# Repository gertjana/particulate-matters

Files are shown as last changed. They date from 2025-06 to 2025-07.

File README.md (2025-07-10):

# Particulate Matter Bike Monitor

This project is a mobile air quality monitoring system designed to be mounted on a bicycle. It measures fine particulate matter (PM1, PM2.5, and PM10) and records GPS location data during your commute. The collected data is stored locally on an SD card and displayed in real-time on an OLED screen, enabling you to create heatmaps of air pollution along your cycling routes.

## Features

- **Real-time air quality monitoring:** Measures PM1, PM2.5, and PM10 concentrations using the BMV080 particulate matter sensor.
- **GPS tracking:** Captures latitude, longitude, and timestamp for each measurement.
- **Local data storage:** Saves measurements to SD card with date-based file organization.
- **Real-time display:** Shows current readings and GPS coordinates on an OLED display.
- **Sensor health monitoring:** Detects when the sensor is obstructed and displays warnings.

## Hardware Requirements

- Arduino-compatible board (ESP32 recommended for SD card support)
- BMV080 Particulate Matter Sensor (I2C)
- GPS module (compatible with TinyGPS++)
- OLED Display (SSD1306, 128x32)
- SD Card Module (SPI)
- Battery pack
- Bicycle mounting hardware

## Pin Configuration

- **I2C (Wire):** SDA, SCL - for BMV080 sensor and OLED display
- **SPI (SD Card):** CS:44, MOSI:9, MISO:8, CLK:7
- **GPS (Software Serial):** TX:3, RX:2

## System Architecture

The system operates on a 10-second measurement interval and includes:

1. **Data Collection:** Reads PM1, PM2.5, PM10, and GPS coordinates
2. **Data Processing:** Packages data into JSON format
3. **Local Storage:** Saves to SD card with date-based filenames
4. **Real-time Display:** Shows current readings on OLED screen

System Architecture

## Data Format

Each measurement is stored as a JSON object with the following structure:

```json
{
  "pm": {
    "pm1": 15,
    "pm2.5": 25,
    "pm10": 45,
    "obstructed": false
  },
  "gps": {
    "date": "15-12-2024",
    "time": "14:30:25",
    "latitude": "52.12345678",
    "longitude": "4.87654321"
  }
}
```

## File Organization

Data is stored on the SD card with the following structure:

- Files are named by date: `DD-MM-YYYY.txt`
- Each line contains one JSON measurement
- Files are created automatically when data is available

## Setup

1. Clone this repository.
2. Install required libraries:
   - SparkFun_BMV080_Arduino_Library
   - TinyGPSPlus
   - ArduinoJson
   - Adafruit_GFX
   - Adafruit_SSD1306
3. Connect hardware according to pin configuration
4. Insert formatted SD card
5. Upload `dust_sensor_new/dust_sensor_new.ino` to your Arduino board
6. Mount the device on your bike and power it up before your ride

## Debug Mode

The system includes comprehensive debug output when `DEBUG` is defined. This includes:

- SD card information (type, size, free space)
- Sensor initialization status
- GPS data processing
- File writing operations

To enable debug mode, ensure `#define DEBUG` is uncommented in the code.

## Data Analysis

### Local Analysis

- Data files can be read directly from the SD card
- JSON format makes it easy to parse with any programming language
- Each measurement includes timestamp and location data

### Heatmap Generation

For setting up and using the heatmap visualization, see [heatmap/README.md](heatmap/README.md)

See [`example.md`](example.md) for sample data format and structure.

## License

MIT License

## Contributing

Contributions are welcome! Please open an issue or submit a pull request.

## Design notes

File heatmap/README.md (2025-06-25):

# Heatmap Visualization

This folder contains scripts to visualize particulate matter measurements on interactive heatmaps.

## Prerequisites
- Python 3.x installed
- pip (Python package installer)
- A JSON file with measurements from The Things Network (provided in `stored_messages_*.json`)

## Setup Instructions

1. Create and activate Python virtual environment:
```fish
# From the project root
python3 -m venv venv

# Activate the virtual environment (for fish shell)
source venv/bin/activate.fish
```

2. Install required packages:
```fish
pip install folium
```

## Generating Heatmaps

Make sure your virtual environment is activated (you should see `(venv)` in your prompt), then:

1. Navigate to this directory:
```fish
cd heatmap
```

2. Run the heatmap generator:
```fish
python create_heatmap.py
```

The script will generate two HTML files:
- `heatmap_pm10_[timestamp].html`: Heatmap showing PM10 concentrations
- `heatmap_pm25_[timestamp].html`: Heatmap showing PM2.5 concentrations

## Viewing the Heatmaps

Open the generated HTML files in a web browser. Each heatmap shows:
- Interactive map with color-coded concentrations
  - Blue: Low concentration
  - Green: Medium-low concentration
  - Yellow: Medium-high concentration
  - Red: High concentration
- Legend box showing:
  - Measurement ranges for each color
  - Total range of measurements
  - Number of samples
- Timestamp in the filename

You can:
- Zoom in/out of the map
- Pan around
- Hover over areas to see concentration intensity

## Managing the Virtual Environment

When you're done, deactivate the virtual environment:
```fish
deactivate
```

To reactivate it later:
```fish
source venv/bin/activate.fish
```

## Input Data Format

The script expects a JSON file (`stored_messages_*.json`) containing measurements from The Things Network with the following structure for each measurement:
```json
{
  "uplink_message": {
    "decoded_payload": {
      "pm10": <number>,
      "pm25": <number>
    },
    "locations": {
      "frm-payload": {
        "latitude": <number>,
        "longitude": <number>
      }
    }
  }
}
```

For more details about the data format and byte structure, see `../example.md`.

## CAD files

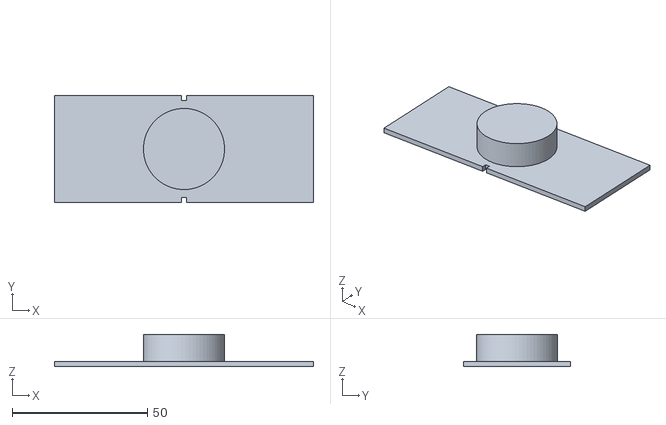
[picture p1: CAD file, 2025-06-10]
3d/Case_Side_Quadlockl_module.stl
95.8 x 39.5 x 12.0

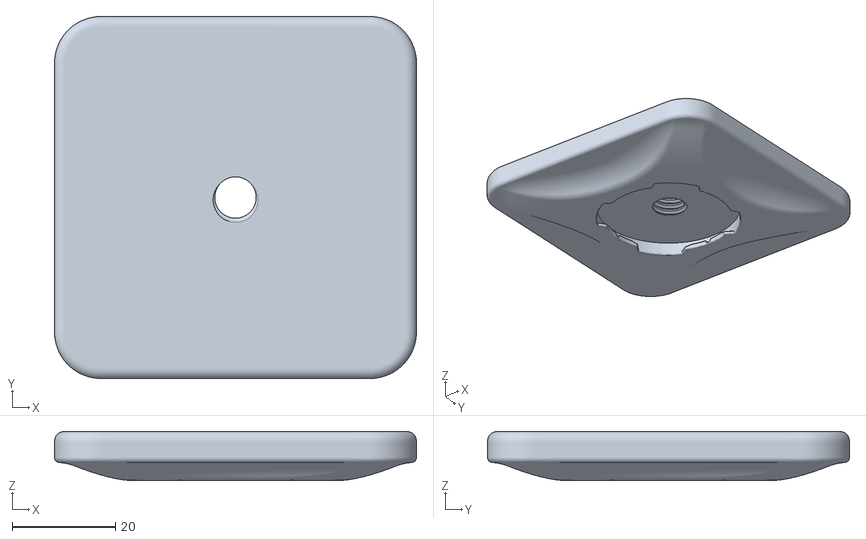
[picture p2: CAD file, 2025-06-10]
3d/quad_lock_adapter_v2.stl
70.0 x 70.0 x 9.50

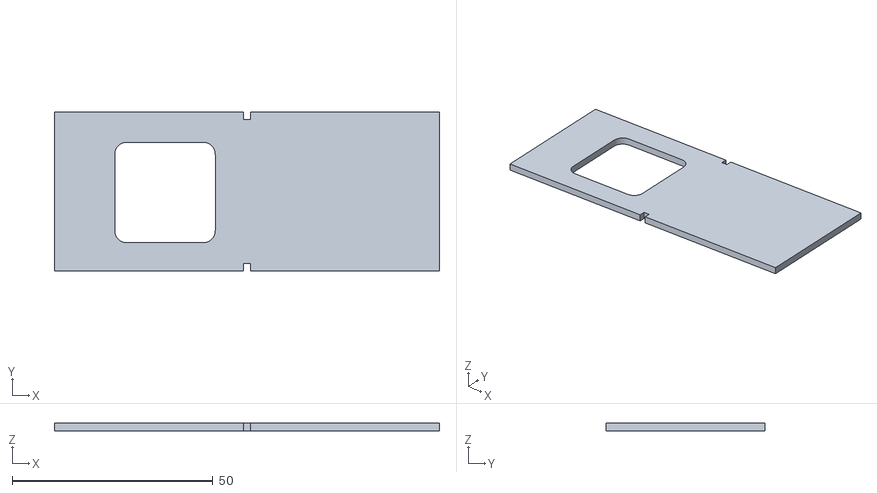
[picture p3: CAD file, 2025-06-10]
3d/Case_Side_GPS_module.stl
95.8 x 39.5 x 2.00

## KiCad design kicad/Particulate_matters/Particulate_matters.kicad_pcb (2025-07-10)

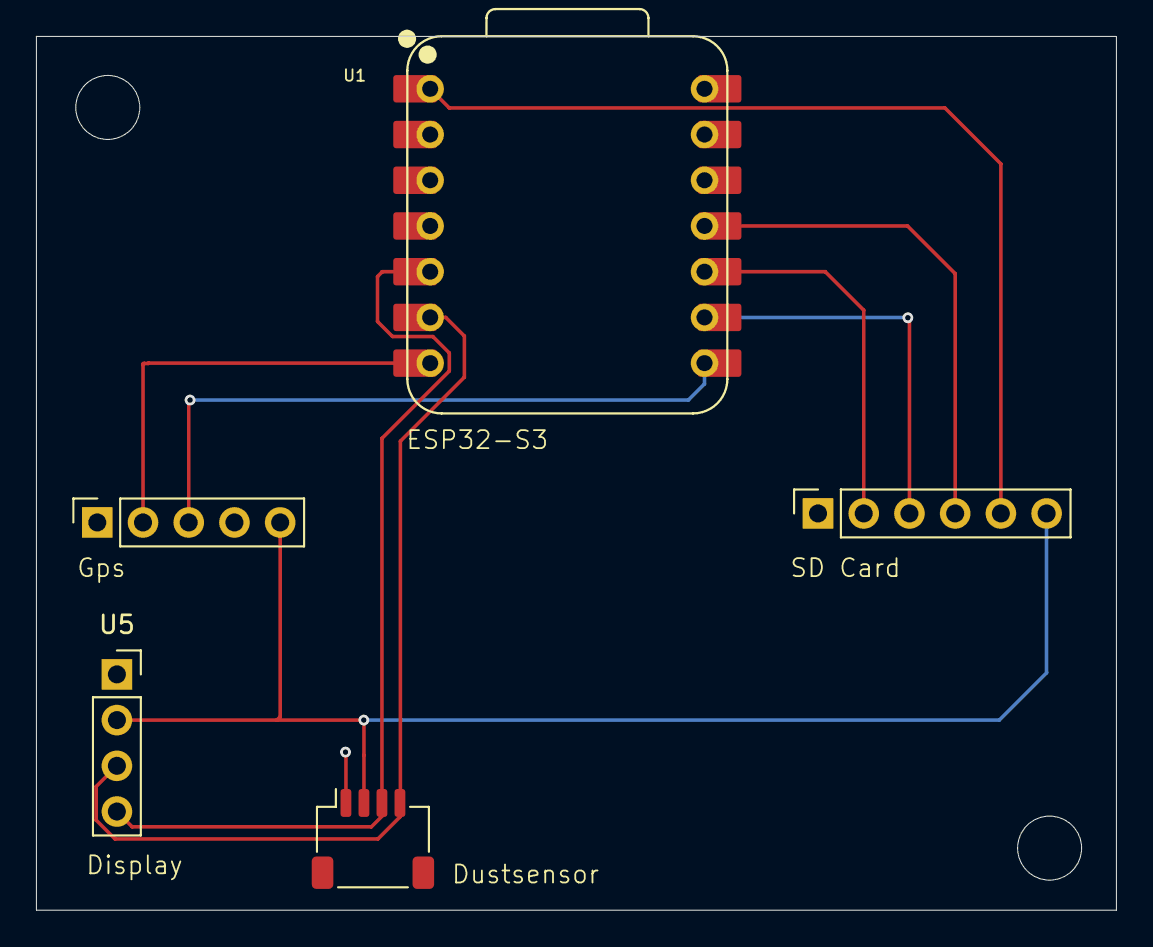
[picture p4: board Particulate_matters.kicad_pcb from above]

Board: 2 copper layers, 60.0 x 48.5 mm, 5 parts (0 on the bottom side), 10 nets.

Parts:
U1: XIAO-ESP32-S3-DIP; XIAO-ESP32S3-DIP
U2: PinSocket_1x05_P2.54mm_Vertical
U3: JST_SH_SM04B-SRSS-TB_1x04-1MP_P1.00mm_Horizontal
U4: PinSocket_1x06_P2.54mm_Vertical
U5: PinSocket_1x04_P2.54mm_Vertical

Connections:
GND: U1.13 (GND), U2.4 (GND), U3.1 (GND), U4.1 (GND), U5.1 (GND)
unnamed: U1.1 (GPIO1/D0/A0), U4.5 (CS)
unnamed: U1.5 (GPIO5/D4/I2C_SDA), U3.3 (SDA), U5.4 (SDA)
unnamed: U1.9 (GPIO7/D8/A8/SCK), U4.3 (CLK)
unnamed: U1.10 (GPIO8/D9/A9/MISO), U4.2 (MISO)
unnamed: U1.6 (GPIO9/D5/I2C_SCL), U3.4 (SDL), U5.3 (SCK)
unnamed: U1.11 (GPIO9/D10/A10/MOSI), U4.4 (MOSI)
unnamed: U1.8 (U0RXD/D7/RX), U2.3 (TX)
unnamed: U1.7 (U0TXD/D6/TX), U2.2 (RX)
VCC: U1.12 (VCC_3V3), U2.5 (VCC), U3.2 (VCC), U4.6 (3V3), U5.2 (VCC)

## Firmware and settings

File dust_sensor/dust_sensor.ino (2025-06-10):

#include <TheThingsNetwork.h>
#include <TinyGPSPlus.h>
#include <SoftwareSerial.h>
#include <math.h>

#include "secrets.h"

#define loraSerial Serial1
#define debugSerial Serial

#define DUST_SENSOR_DIGITAL_PIN_PM10  6
#define DUST_SENSOR_DIGITAL_PIN_PM25  3

#define QUEUE_SIZE 10  // Size of the circular queue
#define DATA_SIZE 20   // Size of each data packet

#define freqPlan TTN_FP_EU868

const int port = 3;
unsigned long lastMeasurement = 0;
const unsigned long MEASURE_INTERVAL = 60000; // Measure every minute

// Circular queue implementation
struct Queue {
    byte data[QUEUE_SIZE][DATA_SIZE];
    int front;
    int rear;
    int count;
};

Queue measurementQueue = {{}, 0, 0, 0};

// Function declarations
void initQueue();
bool isQueueFull();
bool isQueueEmpty();
bool enqueue(byte* data);
bool dequeue(byte* data);
    
TheThingsNetwork ttn(loraSerial, debugSerial, freqPlan);

SoftwareSerial gpsSerial(10, 11);
TinyGPSPlus gps;

typedef union
{
 float number;
 uint8_t bytes[4];
} FLOATUNION_t;

// GPS Values
FLOATUNION_t lat;
FLOATUNION_t lng;
signed int altitude;

//dust sensor variables
float lastDUSTPM25 = 0.0;
float lastDUSTPM10 = 0.0;
unsigned long duration;
unsigned long starttime;
unsigned long endtime;
unsigned long sampletime_ms = 15000;
unsigned long lowpulseoccupancy = 0;
float ratio = 0;
long concentrationPM25 = 0;
long concentrationPM10 = 0;

int cnt = 0;

void setup() {
    pinMode(DUST_SENSOR_DIGITAL_PIN_PM10, INPUT);
    pinMode(DUST_SENSOR_DIGITAL_PIN_PM25, INPUT);
    
    loraSerial.begin(57600);
    debugSerial.begin(9600);
    gpsSerial.begin(9600);

    // Wait a maximum of 10s for Serial Monitor
    while (!debugSerial && millis() < 10000);

    debugSerial.println("-- STATUS");
    ttn.showStatus();

    debugSerial.println("-- JOIN");
    ttn.join(appEui, appKey);

    ttn.onMessage(message);
    initQueue();
}

void loop() {
    measureTask();
    sendTask();
}

void measureTask() {
    if (millis() - lastMeasurement < MEASURE_INTERVAL) {
        return;
    }

    byte data[DATA_SIZE] = {0};
    
    debugSerial.println("-- Measure PM");

    concentrationPM25 = getPM(DUST_SENSOR_DIGITAL_PIN_PM25);
    debugSerial.print("PM25: ");
    debugSerial.println(concentrationPM25);

    if ((ceil(concentrationPM25) != lastDUSTPM25) && ((long)concentrationPM25 > 0)) {
        data[0] = (byte)(concentrationPM25 >> 8);
        data[1] = (byte)concentrationPM25;
        lastDUSTPM25 = ceil(concentrationPM25);
    }

    concentrationPM10 = getPM(DUST_SENSOR_DIGITAL_PIN_PM10);
    debugSerial.print("PM10: ");
    debugSerial.println(concentrationPM10);
    
    if ((ceil(concentrationPM10) != lastDUSTPM10) && ((long)concentrationPM10 > 0)) {
        data[2] = (byte)(concentrationPM10 >> 8);
        data[3] = (byte)concentrationPM10;
        lastDUSTPM10 = ceil(concentrationPM10);
    }

    while (gpsSerial.available()) {
        gps.encode(gpsSerial.read());
    }

    lat.number = gps.location.lat();
    lng.number = gps.location.lng();
    altitude = gps.altitude.meters();

    data[4] = lat.bytes[3];
    data[5] = lat.bytes[2];
    data[6] = lat.bytes[1];
    data[7] = lat.bytes[0];
    
    data[8] = lng.bytes[3];
    data[9] = lng.bytes[2];
    data[10] = lng.bytes[1];
    data[11] = lng.bytes[0];
    
    data[12] = altitude;

    data[13] = gps.date.year() >> 8;
    data[14] = gps.date.year();
    data[15] = gps.date.month();
    data[16] = gps.date.day();
    data[17] = gps.time.hour();
    data[18] = gps.time.minute();
    data[19] = gps.time.second();

    if (enqueue(data)) {
        debugSerial.println("Measurement added to queue");
    } else {
        debugSerial.println("Queue full - measurement dropped");
    }

    lastMeasurement = millis();
}

void sendTask() {
    if (isQueueEmpty()) {
        return;  // Nothing to send
    }

    byte dataToSend[DATA_SIZE];
    
    memcpy(dataToSend, measurementQueue.data[measurementQueue.front], DATA_SIZE);
    
    debugSerial.println("-- Sending...");
    if (ttn.sendBytes(dataToSend, DATA_SIZE, port) == TTN_SUCCESSFUL_TRANSMISSION) {
        byte dummy[DATA_SIZE];
        dequeue(dummy);
        cnt = 0;
    } else {
        debugSerial.println("Transmission failed - keeping message in queue");
        cnt++;
    }
}

void initQueue() {
    measurementQueue.front = 0;
    measurementQueue.rear = 0;
    measurementQueue.count = 0;
}

bool isQueueFull() {
    return measurementQueue.count >= QUEUE_SIZE;
}

bool isQueueEmpty() {
    return measurementQueue.count == 0;
}

bool enqueue(byte* data) {
    if (isQueueFull()) {
        return false;
    }
    
    memcpy(measurementQueue.data[measurementQueue.rear], data, DATA_SIZE);
    measurementQueue.rear = (measurementQueue.rear + 1) % QUEUE_SIZE;
    measurementQueue.count++;
    return true;
}

bool dequeue(byte* data) {
    if (isQueueEmpty()) {
        return false;
    }
    
    memcpy(data, measurementQueue.data[measurementQueue.front], DATA_SIZE);
    measurementQueue.front = (measurementQueue.front + 1) % QUEUE_SIZE;
    measurementQueue.count--;
    return true;
}

void message(const byte* payload, int length, int port) {
    debugSerial.println("-- MESSAGE");
    return;
}

long getPM(int DUST_SENSOR_DIGITAL_PIN) {

  starttime = millis();
  while (1) {
  
    duration = pulseIn(DUST_SENSOR_DIGITAL_PIN, LOW);
    lowpulseoccupancy += duration;
    endtime = millis();
    
    if ((endtime-starttime) > sampletime_ms)
    {
    ratio = (lowpulseoccupancy-endtime+starttime)/(sampletime_ms*10.0);  // Integer percentage 0=>100
    long concentration = 1.1*pow(ratio,3)-3.8*pow(ratio,2)+520*ratio+0.62; // using spec sheet curve

    
    lowpulseoccupancy = 0;
    return(concentration);    
    }
  }  
}

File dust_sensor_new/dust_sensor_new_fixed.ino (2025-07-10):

#include "SparkFun_BMV080_Arduino_Library.h" 
#include <Wire.h>
#include <TinyGPSPlus.h>
#include <SoftwareSerial.h>
#include <ArduinoJson.h>
#include <FS.h>
#include <SD.h>
#include <SPI.h>
#include <Adafruit_GFX.h>
#include <Adafruit_SSD1306.h>

#define SCREEN_WIDTH 128 
#define SCREEN_HEIGHT 32 
#define OLED_RESET     -1 // Reset pin # (or -1 if sharing Arduino reset pin)

#define BMV080_ADDR 0x57
#define wirePort Wire

#define SD_CS 44
#define SD_MOSI 9
#define SD_MISO 8
#define SD_CLK 7

#define GPS_RX 2
#define GPS_TX 3
#define GPS_BAUD 9600

#define INTERVAL 10000 
#define JSON_DOC_SIZE 512  // Explicit JSON document size

#define DEBUG

TinyGPSPlus gps;
SoftwareSerial gpsSerial(GPS_TX, GPS_RX);

SparkFunBMV080 bmv080; 

Adafruit_SSD1306 display(SCREEN_WIDTH, SCREEN_HEIGHT, &Wire, OLED_RESET);

// Global flags for system status
bool sdCardAvailable = false;
bool sensorAvailable = false;
bool displayAvailable = false;

void setup()
{
    Serial.begin(115200);
    while (!Serial && millis() < 10000);

    // Initialize display
    if(!display.begin(SSD1306_SWITCHCAPVCC, 0x3C)) { 
        Serial.println(F("SSD1306 allocation failed"));
    } else {
        displayAvailable = true;
        display.clearDisplay();
        display.setTextSize(1);
        display.setTextColor(WHITE);
        display.println("Particulate Matters");
        display.display();
    }

    // Initialize GPS
    gpsSerial.begin(GPS_BAUD);

    // Initialize SD card
    pinMode(SD_CS, OUTPUT);
    if(!SD.begin()){
        Serial.println("Card Mount Failed");
    } else {
        uint8_t cardType = SD.cardType();
        if(cardType == CARD_NONE){
            Serial.println("No SD card attached");
        } else {
            sdCardAvailable = true;
            #ifdef DEBUG
                Serial.print("SD Card Type: ");
                if(cardType == CARD_MMC){
                    Serial.println("MMC");
                } else if(cardType == CARD_SD){
                    Serial.println("SDSC");
                } else if(cardType == CARD_SDHC){
                    Serial.println("SDHC");
                } else {
                    Serial.println("UNKNOWN");
                }
                
                uint64_t cardSize = SD.cardSize()/(1024*1024);
                Serial.printf("SD Card Size: %lluMB\n", cardSize);
                Serial.printf("SD Free: %lluMB\n", cardSize-(SD.usedBytes()/(1024*1024)));
            #endif
        }
    }

    // Initialize I2C
    wirePort.begin();

    // Initialize BMV080 sensor
    if (bmv080.begin(BMV080_ADDR, wirePort) == false) {
        Serial.println("BMV080 not detected at default I2C address. Check your jumpers and the hookup guide.");
    } else {
        sensorAvailable = true;
        #ifdef DEBUG
            Serial.println("BMV080 found!");
        #endif

        bmv080.init();

        if (bmv080.setMode(SF_BMV080_MODE_CONTINUOUS) == true) {   
            #ifdef DEBUG
                Serial.println("BMV080 set to continuous mode");
            #endif  
        } else {
            Serial.println("Error setting BMV080 mode");
            sensorAvailable = false;
        }
    }

    // Display system status
    if (displayAvailable) {
        display.clearDisplay();
        display.setCursor(0,0);
        display.println("System Status:");
        display.printf("SD: %s\n", sdCardAvailable ? "OK" : "FAIL");
        display.printf("Sensor: %s\n", sensorAvailable ? "OK" : "FAIL");
        display.display();
        delay(2000);
    }
}

String zeroPad(int number, int width) {
    char buffer[10];
    if (width > 9) width = 9; // Prevent buffer overflow
    sprintf(buffer, "%0*d", width, number);
    return String(buffer);
}

bool appendFile(fs::FS &fs, JsonDocument &doc) {
    if (!sdCardAvailable) {
        return false;
    }
    
    if (!doc["gps"]["date"]) { 
        return false;
    }
    
    String path = String("/") + String(doc["gps"]["date"]) + String(".txt");
    
    #ifdef DEBUG
        Serial.printf("Writing to %s\n", path.c_str()); 
    #endif
    
    char output[256];
    if (serializeJson(doc, output, sizeof(output)) == 0) {
        Serial.println("JSON serialization failed");
        return false;
    }
    
    File file = fs.open(path.c_str(), FILE_APPEND);
    if(!file){
        Serial.printf("Failed to open file for appending, creating %s\n", path.c_str());
        File file2 = fs.open(path.c_str(), FILE_WRITE);
        if (!file2) {
            Serial.println("Failed to create new file");
            return false;
        }
        file2.println(output);
        file2.close();
    } else {
        file.println(output);
        file.close();
    }
    
    return true;
}

void getGPS(JsonDocument &doc) {
    JsonObject gpsObj = doc.createNestedObject("gps");
    bool hasValidData = false;
    
    while (gpsSerial.available() > 0) {
        #ifdef DEBUG
            Serial.print(char(gpsSerial.peek()));
        #endif

        if (gps.encode(gpsSerial.read())) {
            if (gps.date.isValid()) {
                gpsObj["date"] = zeroPad(gps.date.day(), 2) + "-" + zeroPad(gps.date.month(), 2) + "-" + String(gps.date.year());
                hasValidData = true;
            }
            if (gps.time.isValid()) {
                gpsObj["time"] = zeroPad(gps.time.hour(), 2) + ":" + zeroPad(gps.time.minute(), 2) + ":" + zeroPad(gps.time.second(), 2);
                hasValidData = true;
            }
            if (gps.location.isValid()) {
                gpsObj["latitude"] = String(gps.location.lat(), 8);
                gpsObj["longitude"] = String(gps.location.lng(), 8);
                hasValidData = true;
            }
        }
    }

    #ifdef DEBUG
        if (hasValidData) {
            Serial.println("GPS data updated");
        }
        Serial.println();
    #endif
}

void getPM(JsonDocument &doc) {
    JsonObject pmObj = doc.createNestedObject("pm");

    if (sensorAvailable && bmv080.readSensor()) {
        pmObj["pm1"] = bmv080.PM1();
        pmObj["pm2.5"] = bmv080.PM25();
        pmObj["pm10"] = bmv080.PM10();
        pmObj["obstructed"] = bmv080.isObstructed();
    }
}
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

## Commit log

2018-02-22 Arduino sketch to send ppd42 sensor data through lora
2025-06-03 Added temperature
2025-06-04 Removed Temperature, it was not needed in the calculations and took too much space in the box
    [dust_sensor.ino]
2025-06-08 Added 3d files for the case modifications
    [Case_Side_GPS_module.stl, Case_Side_Quadlockl_module.stl, quad_lock_adapter_v2.stl]
2025-06-24 Added Kicad Project
    [Particulate_matters.kicad_pcb, Particulate_matters.kicad_sch]
2025-06-25 Added a python script to generate heatmap's from the messages
2025-06-25 Updated readme, heatmap has a legend and SF12 for the lora communication
2025-07-06 New version with XIAO ESP32S3, ATGM336H GPS and BMV080 PM Sensor
2025-07-06 Updated schematic and pcb design
    [Particulate_matters.kicad_pcb]
2025-07-10 updated pcb
    [Particulate_matters-B_Cu.gbr, Particulate_matters-B_Mask.gbr, Particulate_matters-B_Paste.gbr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]
2025-07-10 AI updated version in _fixed.ino, readme now uses the svg diagram
    [Particulate_matters.kicad_pcb, Particulate_matters.kicad_sch]
2025-07-10 ignring kicad locks and backups
